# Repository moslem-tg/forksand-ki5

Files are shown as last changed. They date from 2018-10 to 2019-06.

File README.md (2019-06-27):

# ki5 RISC-V PCB in KiCAD

The ki5 board is a KiCAD port of SiFive's HiFive Unleashed board for the
RISC-V processor.

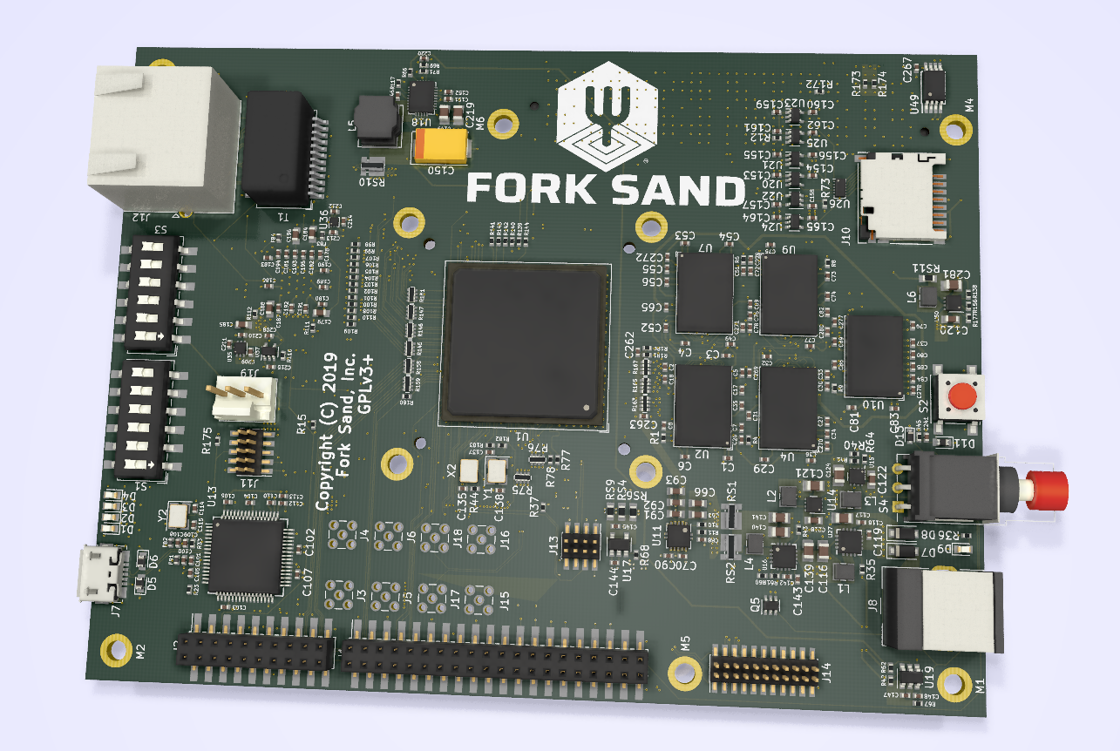
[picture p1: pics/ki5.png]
ki5 pic


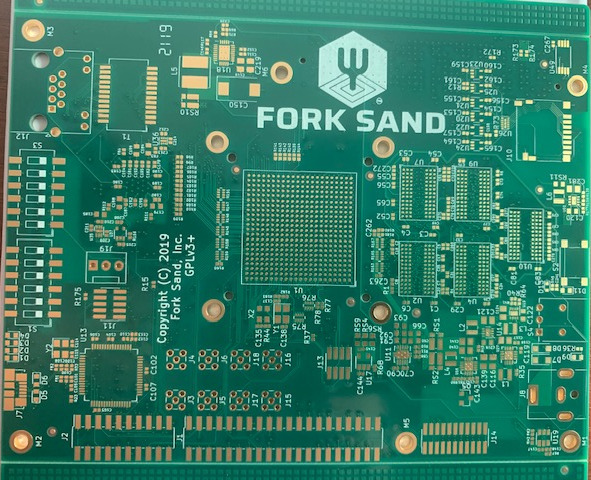
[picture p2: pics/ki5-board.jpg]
ki5 board pic


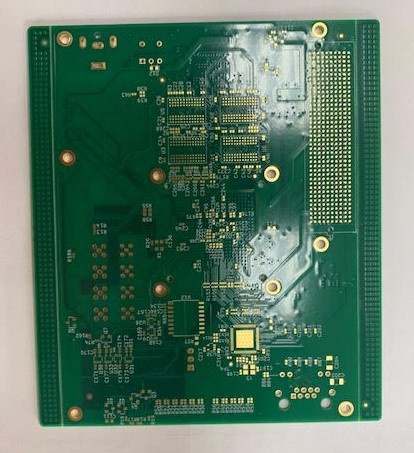
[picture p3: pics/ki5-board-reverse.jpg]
ki5 board reverse pic


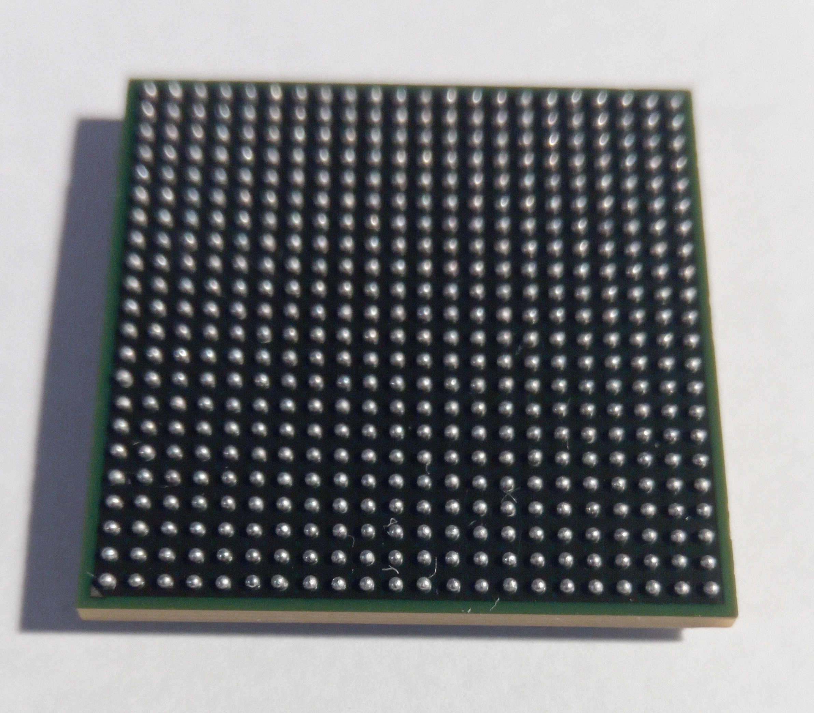
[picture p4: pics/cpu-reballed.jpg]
reballed cpu pic


First draft done for:

* Ethernet
* FMC Connector
* Power Supply
* USB to UART and JTAG
* Freedom U540 IO and Power
* DDR 4x8 32 bits
* DDR 4x8 32 bit and ECC
* Freedom U540 DDR and Chiplink
* First draft of the Board

It remains to finish and check power circuits for this list.

The second draft, release of the Board in progress.

(C) 2018, 2019, Fork Sand, Inc.

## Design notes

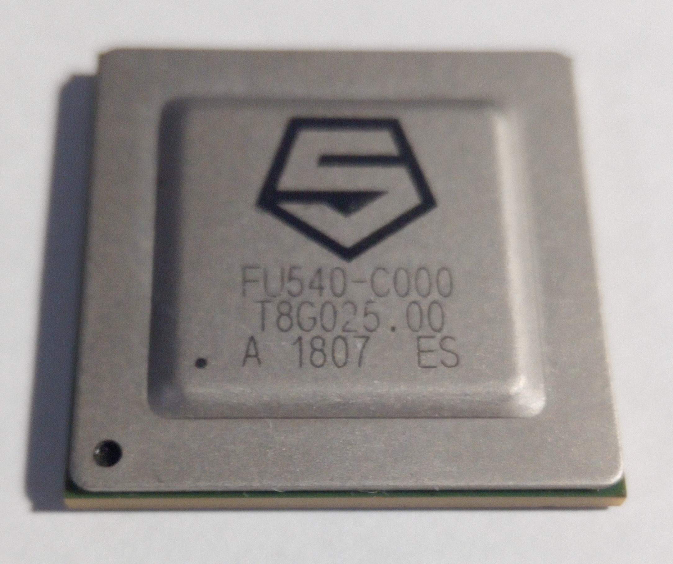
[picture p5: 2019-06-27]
pics/cpu-front.jpg

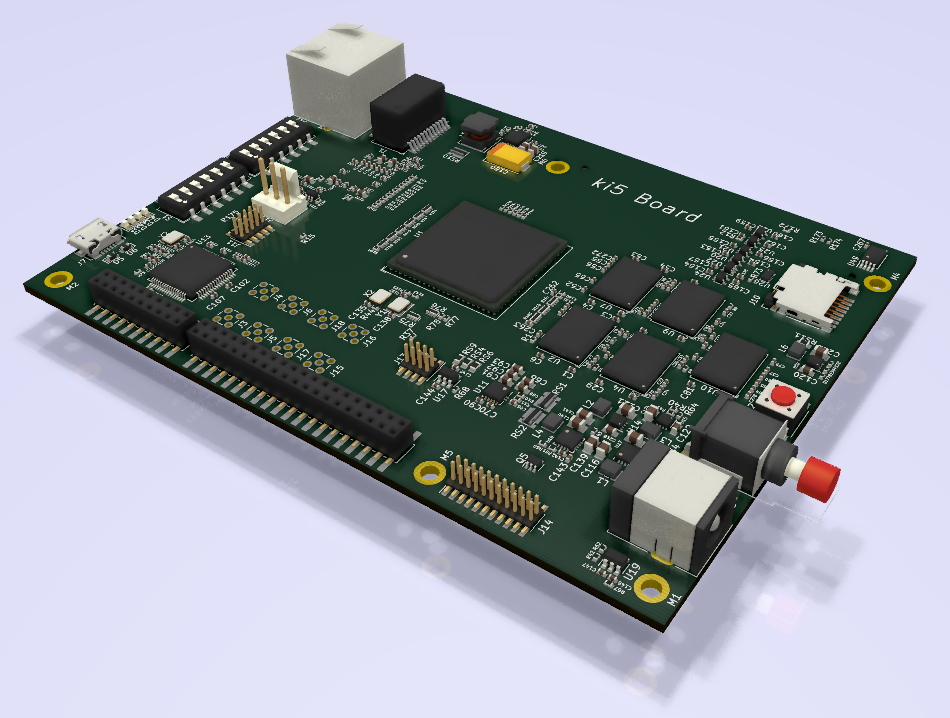
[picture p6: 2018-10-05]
3D/ki5_1.png

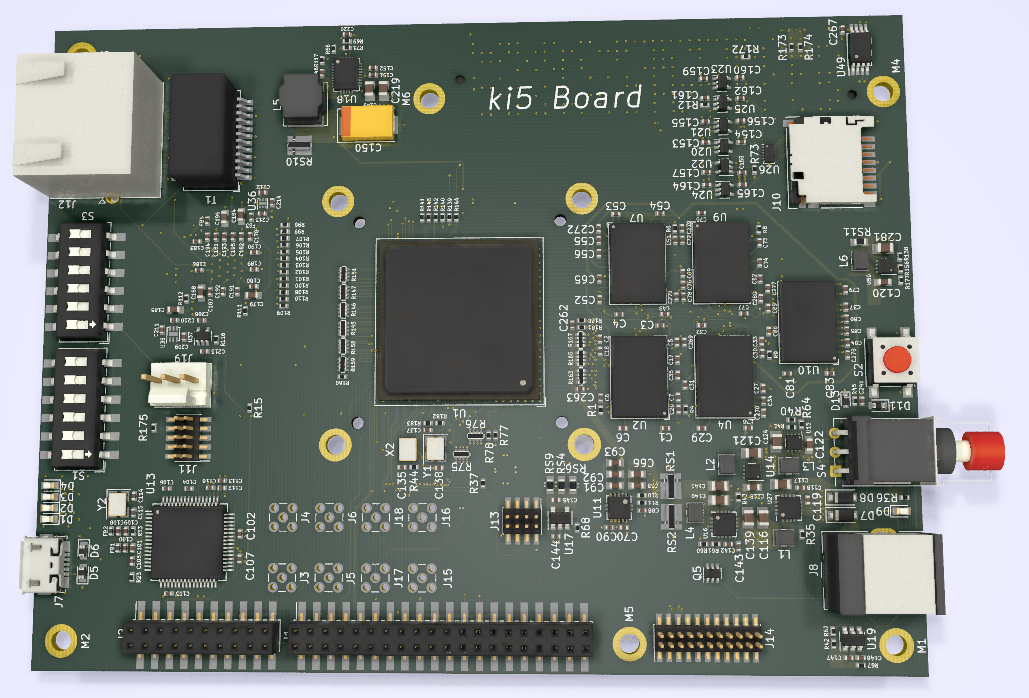
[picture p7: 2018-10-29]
3D/part of lines.png

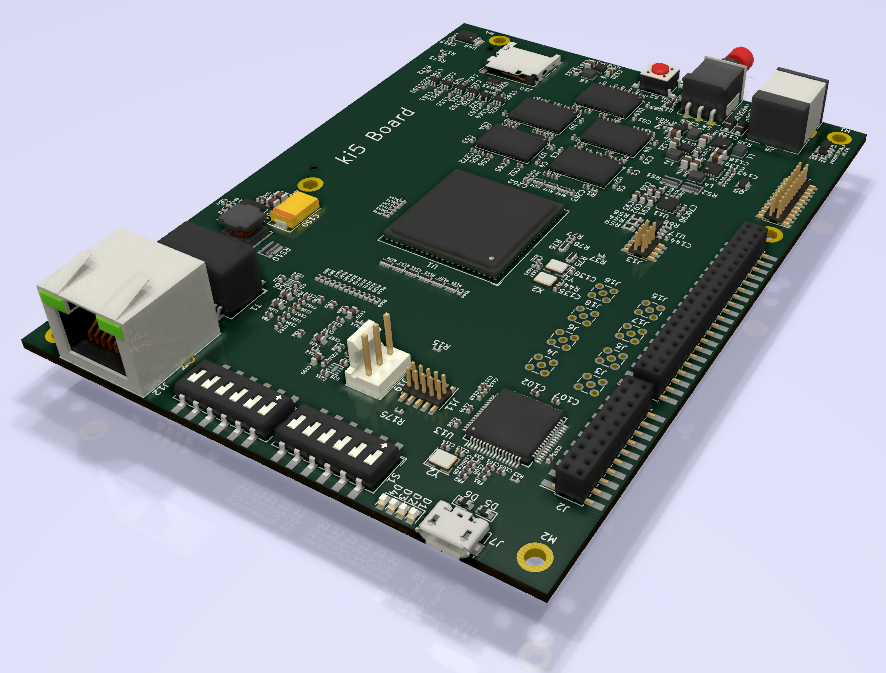
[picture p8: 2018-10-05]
3D/ki5_2.png

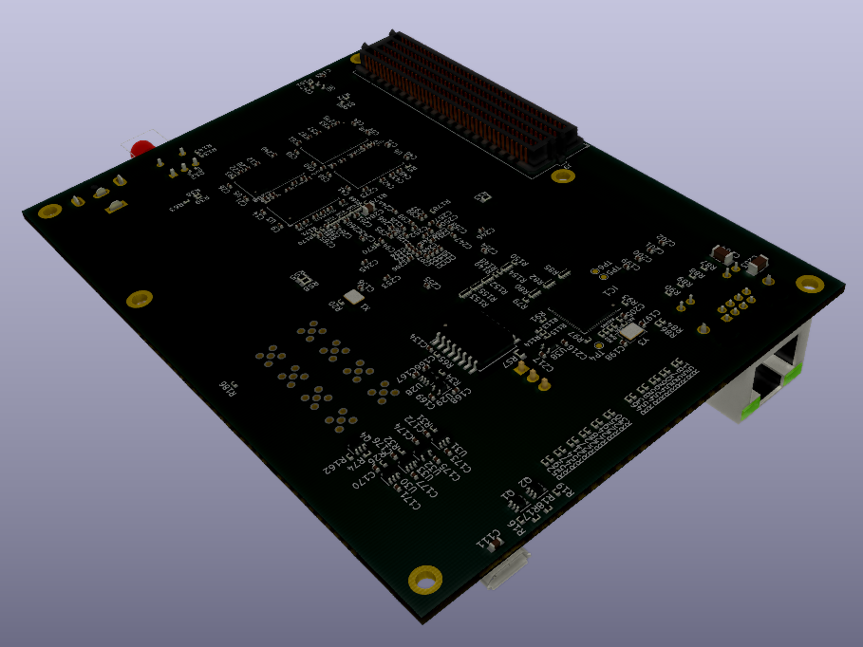
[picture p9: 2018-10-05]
3D/ki5_3.png

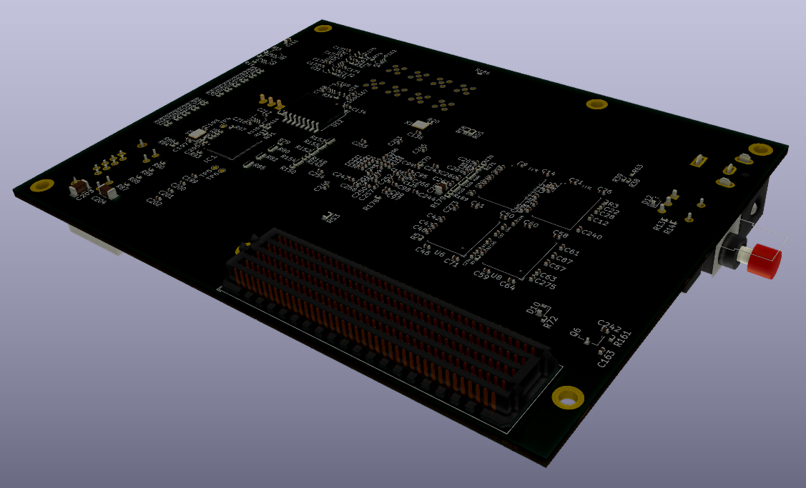
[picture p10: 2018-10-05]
3D/ki5_4.png

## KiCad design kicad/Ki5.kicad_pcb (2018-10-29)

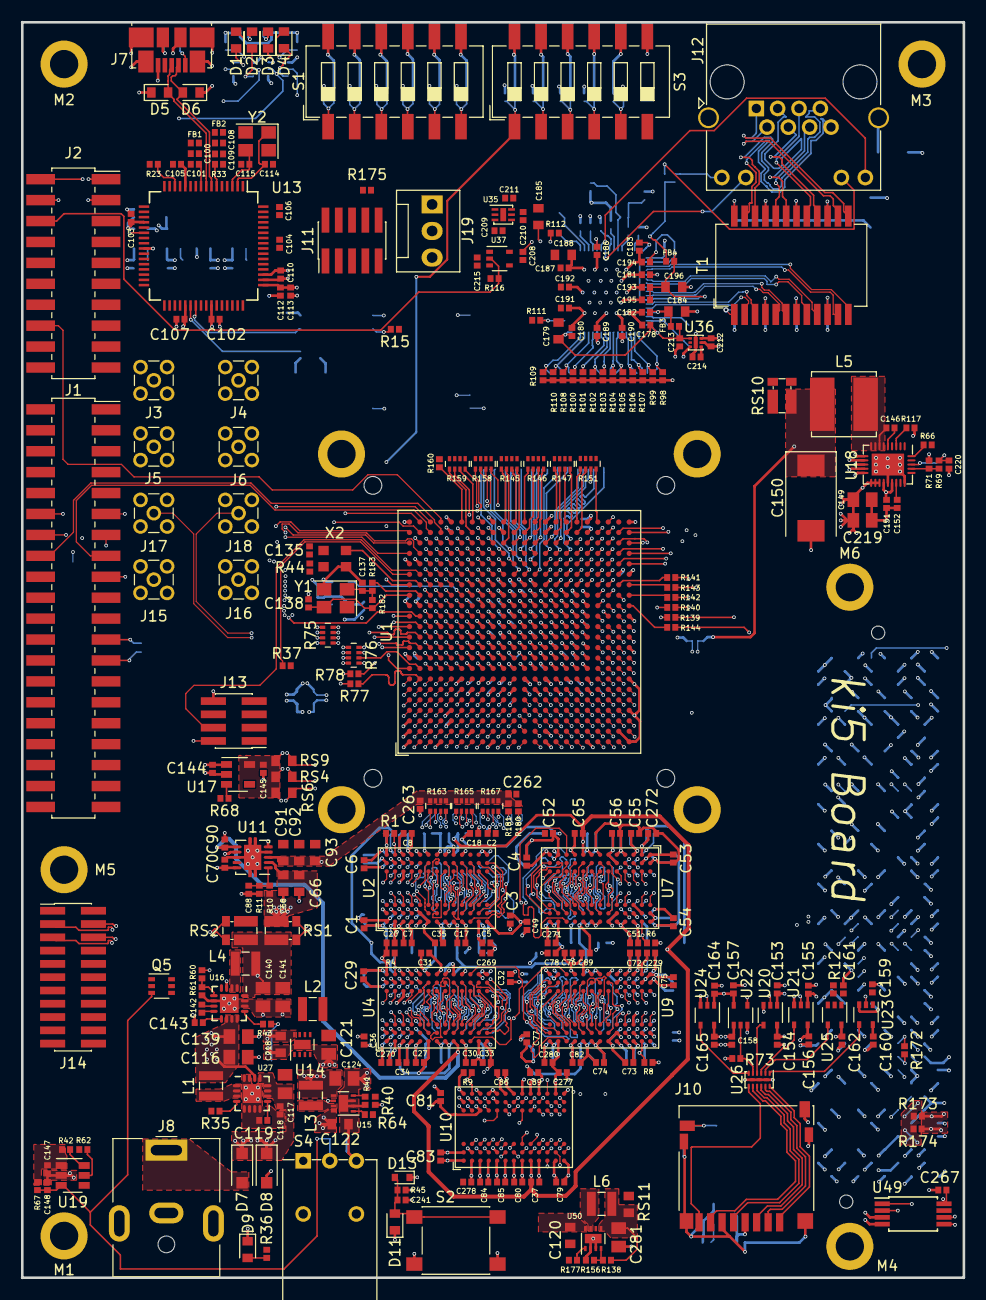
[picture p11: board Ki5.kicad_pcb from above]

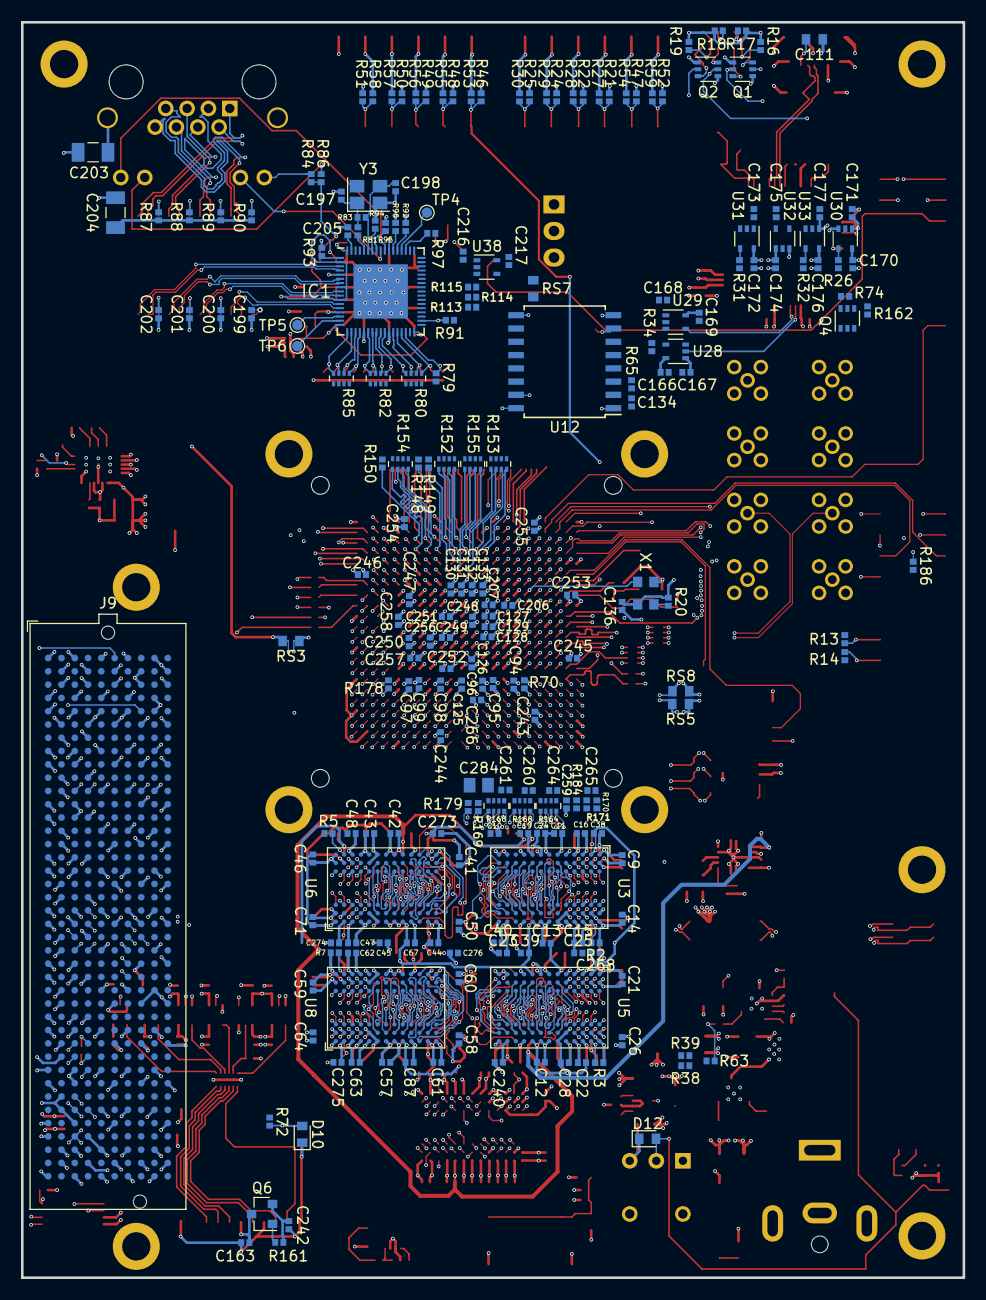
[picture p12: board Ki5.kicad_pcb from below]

Board: 10 copper layers, 90.0 x 120.0 mm, 542 parts (227 on the bottom side), 569 nets.

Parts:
C1, C6, C9, C14, C21, C26, C29, C34, C41, C46, C49, C54, C57, C62, C70, C71, C76, C79, C84, C94, C95, C96, C97, C100, C108, C112, C130, C131, C151, C163, C213, C243, C244, C245, C246, C247, C248, C249, C250, C251, C252: 4.7uF; C_0402_1005Metric
C2, C3, C4, C5, C7, C8, C10, C11, C12, C13, C15, C16, C17, C19, C22, C23, C24, C25, C27, C28, C30, C31, C32, C33, C35, C36, C37, C39, C42, C43, C44, C45, C47, C48, C50, C51, C52, C53, C55, C56, C58, C59, C60, C61, C63, C64, C65, C67, C69, C72, C73, C74, C75, C77, C78, C80, C81, C82, C83, C85, C86, C87, C89, C90, C98, C99, C101, C102, C103, C104, C105, C106, C107, C109, C110, C113, C118, C125, C126, C127, C129, C132, C133, C134, C135, C136, C146, C147, C153, C154, C155, C156, C157, C158, C159, C160, C161, C162, C164, C165, C166, C167, C168, C169, C170, C171, C172, C173, C174, C175, C176, C177, C178, C179, C181, C182, C183, C186, C188, C189, C190, C191, C192, C193, C194, C195, C199, C200, C201, C202, C206, C207, C208, C211, C214, C215, C216, C217, C220, C253, C254, C255, C256, C257, C258, C259, C260, C261, C262, C263, C264: 0.1uF; C_0402_1005Metric
C18, C20, C38, C40, C128, C144, C145, C209, C210, C212, C240, C242, C268, C269, C270, C271, C272, C273, C274, C275, C276, C277, C278, C279, C280: 1uF; C_0402_1005Metric
C66, C68, C91, C92, C93, C120, C122, C180, C184, C185, C187, C196, C218: 10uF; C_0603_1608Metric
C88: 1nF; C_0402_1005Metric
C111: 4.7uF; C_0603_1608Metric
C114, C115, C137, C138, C197, C198: 18pF; C_0402_1005Metric
C116, C121, C124, C139, C140, C141, C281: 22uF; C_0805_2012Metric
C117, C149, C219: 10uF; C_0805_2012Metric
C119: 33nF; C_0402_1005Metric
C142, C143, C148, C152, C205, C241, C265: 10nF; C_0402_1005Metric
C150: 220uF; CP_EIA-7343-20_Kemet-V
C203, C204: 1000pF, 2KV; C_1206_3216Metric
C266: 2.2pF; C_0402_1005Metric
C267: DNP; C_0402_1005Metric
C284: 0.1uF; C_0805_2012Metric
D1, D2, D3, D4, D9: Green; LED_0603_1608Metric
D5, D6, D10, D11, D12: PGB1010603NRHF; D_0603_1608Metric
D7: DB2W40300L; D_SOD-123F
D8: SMF12A; D_SOD-123F
D13: 1N4148WT; D_SOD-523
FB1, FB2, FB3, FB4: 120R; L_0402_1005Metric
IC1: VSC8541XMV-01; QFN-68-1EP_8x8mm_P0.4mm_EP5.2x5.2mm
J1: Conn_02x20_Odd_Even; PinSocket_2x20_P2.00mm_Vertical_SMD
J2: Conn_02x10_Odd_Even; PinSocket_2x10_P2.00mm_Vertical_SMD
J3, J4, J5, J6, J15, J16, J17, J18: Conn_Coaxial; MMCX_Molex_73415-1471_Vertical
J7: USB_B_Micro; USB_Micro-B_Molex_47346-0001
J8: Jack-DC; BarrelJack_CUI_PJ-063AH_Horizontal
J9: ASP-134602-01; Samtec_FMC_ASP-134602-01_10x40_P1.27mm_Vertical
J10: Micro_SD_Card_Det; microSD_HC_Hirose_DM3D-SF
J11: Conn_02x05_Odd_Even; PinHeader_2x05_P1.27mm_Vertical_SMD
J12: RJHSE5384; RJ45_Amphenol_RJHSE538X
J13: Conn_02x04_Odd_Even; PinHeader_2x04_P1.27mm_Vertical_SMD
J14: Conn_02x11_Odd_Even; PinHeader_2x11_P1.27mm_Vertical_SMD
J19: Fan_Tacho; FanPinHeader_1x03_P2.54mm_Vertical
L1: 1.0uH; L_Wuerth_MAPI-2512
L2, L3, L6: 2.2uH; L_Wuerth_MAPI-2512
L4: 0.47uH; L_Wuerth_MAPI-2510
L5: 1.0uH; L_Bourns_SRN6045TA
M1, M2, M3, M4, M5, M6: Mounting_Hole_PAD; MountingHole_2.7mm_M2.5_ISO7380_Pad
Q1, Q2, Q4, Q5: FDG6335N; SOT-363_SC-70-6
Q6: IRLML6402; SOT-23
R1, R2, R3, R4, R5, R6, R7, R8, R9, R70: 240R; R_0402_1005Metric
R10, R11, R107, R109, R111, R115: 10K; R_0402_1005Metric
R12, R20, R37, R40, R42, R44, R45, R62, R67, R69, R72, R74, R116, R161, R162: 100K; R_0402_1005Metric
R13, R14, R93: 2K; R_0402_1005Metric
R15: 47K; R_0402_1005Metric
R16, R17, R18, R19, R36, R84, R86: 330R; R_0402_1005Metric
R21, R22, R24, R25, R47, R52, R53, R55, R56, R57, R58, R73, R96, R113, R114: 4.7K; R_0402_1005Metric
R23, R33: 12K; R_0402_1005Metric
R26, R31, R32, R34: 1K; R_0402_1005Metric
R27, R28, R29, R30, R35, R46, R48, R49, R50, R51, R54, R59, R97, R98, R99, R100, R101, R102, R103, R104, R105, R106, R108, R110, R112: DNP; R_0402_1005Metric
R38: 210K; R_0402_1005Metric
R39, R41, R156: 33.2K; R_0402_1005Metric
R43, R63, R64, R65, R66, R68, R92, R94, R95, R117, R172, R173, R174, R175, R177, R183, R186: 0R; R_0402_1005Metric
R60: 80.6K; R_0402_1005Metric
R61: 160K; R_0402_1005Metric
R71: 82K; R_0402_1005Metric
R75, R76, R80, R82, R85, R145, R146, R147, R151, R152, R153, R154, R155, R158, R159: 33R; R_Array_Concave_4x0402
R77, R78, R79, R91, R139, R140, R141, R142, R143, R144, R148, R149, R150, R160: 33R; R_0402_1005Metric
R81: 39R; R_0402_1005Metric
R83, R182: 1M; R_0402_1005Metric
R87, R88, R89, R90, R178: 75R; R_0402_1005Metric
R138: 154K; R_0402_1005Metric
R163, R164, R165, R166, R167, R168: 49R9; R_Array_Convex_4x0402
R169, R170, R171, R179, R180, R181, R184: 49R9; R_0402_1005Metric
RS1, RS2, RS10: 0R001; R_Shunt_Vishay_WSKW0612
RS3, RS4, RS5, RS6, RS7, RS8, RS9: 0R20; R_0603_1608Metric
RS11: 0R02; R_0603_1608Metric
S1: SW DIP-6; SW_DIP_SPSTx06_Slide_6.7x16.8mm_W8.61mm_P2.54mm_LowProfile
S2: SW_Push; SW_SPST_PTS645
S3: DNP; SW_DIP_SPSTx06_Slide_6.7x16.8mm_W8.61mm_P2.54mm_LowProfile
S4: SW_Push_SPDT; SW_NKK_BB15AH
T1: TG111-MSC13LF; Transformer_Ethernet_HALO_TG111-MSC13
TP4, TP5, TP6: Test_Point; TestPoint_Pad_D1.0mm
U1: FU540-C000; BGA-484_23.0x23.0mm_Layout22x22_P1.0mm
U2, U3, U4, U5, U6, U7, U8, U9, U10: H5AN8G8NAFR-UH; FBGA-78_7.5x11mm_Layout2x3x13_P0.8mm
U11: TPS51200DRC; Texas_S-PVSON-N10
U12: IS25WP256D; SOIC-16W_7.5x10.3mm_P1.27mm
U13: FT2232HL; LQFP-64_10x10mm_P0.5mm
U14, U50: TLV62080DSGx; WSON-8-1EP_2x2mm_P0.5mm_EP0.9x1.6mm
U15: TLV62084DSGx; WSON-8-1EP_2x2mm_P0.5mm_EP0.9x1.6mm
U16: TLV62095RGTR; QFN-16-1EP_3x3mm_P0.5mm_EP1.8x1.8mm
U17: LP5907MFX-1.8/NOPB; SOT-23-5
U18: TPS51363; Texas_R-VFQFN-28-1EP_3.5x4.5mm_P0.4mm_EP2.1x3.1mm
U19: LM3880MFE-1AA/NOPB; SOT-23-6
U20, U21, U22, U23, U24, U25, U28, U29, U30, U31, U32, U33, U37, U38: SN74AUP1T34DCKR; SOT-353_SC-70-5
U26: TPD6F003; Texas_R-PWSON-N12_EP0.4x2mm
U27: TPS62133RGTT; QFN-16-1EP_3x3mm_P0.5mm_EP1.8x1.8mm
U35: MIC5353-2.5YMT-TR; MLF-6-1EP_1.6x1.6mm_P0.5mm_EP0.5x1.26mm
U36: NCP133AMX100TCG; DFN-6-1EP_1.2x1.2mm_P0.4mm_EP0.3x0.94mm
U49: M24C02-WMN; TSSOP-8_4.4x3mm_P0.65mm
X1: 33.3333 MHz; Oscillator_SMD_EuroQuartz_XO32-4Pin_3.2x2.5mm
X2: 1.0 MHz; Oscillator_SMD_EuroQuartz_XO32-4Pin_3.2x2.5mm
Y1: 33.333 MHz; Crystal_SMD_3225-4Pin_3.2x2.5mm
Y2: 12 MHz; Crystal_SMD_Abracon_ABM8G-4Pin_3.2x2.5mm
Y3: 25 MHz; Crystal_SMD_SeikoEpson_FA238-4Pin_3.2x2.5mm

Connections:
+1V0: C178.1, C179.1, C180.2, C213.1, FB3.1, IC1.17, IC1.34, U36.1
+1V2: C1.2, C2.2, C3.2, C4.2, C5.2, C6.2, C7.2, C8.2, C9.2, C10.2, C11.2, C12.2, C13.2, C14.2, C15.2, C16.2, C21.2, C22.2, C23.2, C24.2, C25.2, C26.2, C27.2, C28.2, C29.2, C30.2, C31.2, C32.2, C33.2, C34.2, C35.2, C36.2, C41.2, C42.2, C43.2, C44.1, C45.2, C46.2, C47.2, C48.2, C49.2, C50.2, C51.2, C52.2, C53.2, C54.2, C55.2, C56.2, C57.2, C58.2, C59.2, C60.2, C61.2, C62.2, C63.2, C64.2, C66.2, C68.2, C71.2, C72.2, C73.2, C74.2, C75.2, C76.2, C77.2, C78.2, C79.2, C80.2, C81.2, C82.2, C83.2, C84.2, C85.2, C86.2, R10.1, RS1.1, U2.A1, U2.B2, U2.B8, U2.C1, U2.C7, U2.C9, U2.E2, U2.E8, U2.F1, U2.F9, U2.H1, U2.J9, U2.M1, U2.N9, U3.A1, U3.B2, U3.B8, U3.C1, U3.C7, U3.C9, U3.E2, U3.E8, U3.F1, U3.F9, U3.H1, U3.J9, U3.M1, U3.N9, U4.A1, U4.B2, U4.B8, U4.C1, U4.C7, U4.C9, U4.E2, U4.E8, U4.F1, U4.F9, U4.H1, U4.J9, U4.M1, U4.N9, U5.A1, U5.B2, U5.B8, U5.C1, U5.C7, U5.C9, U5.E2, U5.E8, U5.F1, U5.F9, U5.H1, U5.J9, U5.M1, U5.N9, U6.A1, U6.B2, U6.B8, U6.C1, U6.C7, U6.C9, U6.E2, U6.E8, U6.F1, U6.F9, U6.H1, U6.J9, U6.M1, U6.N9, U7.A1, U7.B2, U7.B8, U7.C1, U7.C7, U7.C9, U7.E2, U7.E8, U7.F1, U7.F9, U7.H1, U7.J9, U7.M1, U7.N9, U8.A1, U8.B2, U8.B8, U8.C1, U8.C7, U8.C9, U8.E2, U8.E8, U8.F1, U8.F9, U8.H1, U8.J9, U8.M1, U8.N9, U9.A1, U9.B2, U9.B8, U9.C1, U9.C7, U9.C9, U9.E2, U9.E8, U9.F1, U9.F9, U9.H1, U9.J9, U9.M1, U9.N9, U10.A1, U10.B2, U10.B8, U10.C1, U10.C7, U10.C9, U10.E2, U10.E8, U10.F1, U10.F9, U10.H1, U10.J9, U10.M1, U10.N9, U11.2
+2V5: C185.2, C186.1, C208.1, C210.2, C216.1, FB4.1, IC1.58, R84.2, R86.2, R112.1, U35.4, U37.5, U38.1
+3.3VA: C163.2, J10.4, Q6.3
+3.3VP: C267.2, J9.D32, U49.8
+3V3: C70.2, C102.2, C103.2, C104.2, C110.2, C121.2, C144.1, C154.1, C156.1, C158.1, C160.1, C162.1, C165.1, C167.2, C169.2, C171.2, C173.2, C175.2, C177.2, C209.2, C242.2, FB1.2, FB2.2, L2.2, Q6.2, R16.1, R17.1, R18.1, R19.1, R23.1, R36.2, R38.2, R73.1, R74.2, R161.2, U11.7, U11.10, U13.20, U13.31, U13.42, U13.50, U13.56, U14.5, U17.1, U20.5, U21.5, U22.1, U23.5, U24.5, U25.5, U28.1, U29.5, U30.1, U31.1, U32.5, U33.1, U35.1, U35.3
+5V: C116.2, C120.2, C122.2, C139.2, C147.2, C151.1, C214.1, C218.2, J1.3, L1.2, R35.2, R42.2, R62.2, R67.2, U14.8, U15.8, U16.3, U16.10, U16.11, U16.12, U18.18, U18.20, U19.1, U27.14, U36.4, U50.8
+12V: C117.2, C118.2, C149.2, C219.2, D7.1, D8.1, J1.4, J1.6, J19.2, R173.2, R174.2, U18.15, U18.16, U18.17, U27.10, U27.11, U27.12, U27.13
/DDR4_x8_32b_1/REFIN: C88.1, R10.2, R11.1, U11.1
/Ethernet/CLKOUT: IC1.54, R97.2, R112.2
/Ethernet/CLK_SQUELCH_IN: IC1.57, R96.1
/Ethernet/COL: IC1.18, R85.4, R98.2
/Ethernet/CRS: IC1.19, R85.3, R99.2
/Ethernet/ELED0: IC1.60, J12.10
/Ethernet/ELED1: IC1.59, J12.12
/Ethernet/FASTLINK_FAIL_2V5: IC1.52, U38.2
/Ethernet/GEMGXL_MDINT: IC1.51, R115.2
/Ethernet/GEMGXL_RST_2V5: IC1.53, U37.4
/Ethernet/MX1_N: J12.7, T1.22
/Ethernet/MX1_P: J12.8, T1.23
/Ethernet/MX2_N: J12.3, T1.19
/Ethernet/MX2_P: J12.6, T1.20
/Ethernet/MX3_N: J12.4, T1.16
/Ethernet/MX3_P: J12.5, T1.17
/Ethernet/MX4_N: J12.1, T1.13
/Ethernet/MX4_P: J12.2, T1.14
/Ethernet/P0_D0_N: IC1.12, T1.3
/Ethernet/P0_D0_P: IC1.13, T1.2
/Ethernet/P0_D1_N: IC1.9, T1.6
/Ethernet/P0_D1_P: IC1.10, T1.5
/Ethernet/P0_D2_N: IC1.6, T1.9
/Ethernet/P0_D2_P: IC1.7, T1.8
/Ethernet/P0_D3_N: IC1.3, T1.12
/Ethernet/P0_D3_P: IC1.4, T1.11
/Ethernet/RXD0: IC1.29, R80.3, R100.2
/Ethernet/RXD1: IC1.27, R80.4, R101.2
/Ethernet/RXD2: IC1.26, R82.1, R102.2
/Ethernet/RXD3: IC1.25, R82.2, R103.2
/Ethernet/RXD4: IC1.24, R82.3, R104.2
/Ethernet/RXD5: IC1.23, R82.4, R105.2
/Ethernet/RXD6: IC1.21, R85.1, R106.2
/Ethernet/RXD7: IC1.20, R85.2, R107.2
/Ethernet/RX_CLK: IC1.32, R79.1, R109.2
/Ethernet/RX_DV: IC1.30, R80.2, R108.2
/Ethernet/RX_ER: IC1.31, R80.1, R110.2
/Ethernet/TX_CLK: IC1.36, R91.1, R111.2
/FMC.sch/FMC_GA0: J9.C34, U49.1
/FMC.sch/FMC_GA1: J9.D35, U49.2
/FMC.sch/FMC_SCL: J9.C30, U49.6
/FMC.sch/FMC_SDA: J9.C31, U49.5
/FT2232/FT_JTAG_SRST: Q4.6, R74.1, U13.22
/FT2232/FT_JTAG_TCK: U13.16, U30.2
/FT2232/FT_JTAG_TDI: U13.17, U31.2
/FT2232/FT_JTAG_TDO: U13.18, U32.4
/FT2232/FT_JTAG_TMS: U13.19, U33.2
/FT2232/FT_UART_RX: U13.39, U29.4
/FT2232/FT_UART_TX: U13.38, U28.2
/FT2232/USB_D_N: D6.2, J7.2, U13.7
/FT2232/USB_D_P: D5.2, J7.3, U13.8
/FT2232/VPHY_FT: C108.2, C109.2, FB2.1, U13.4
/FT2232/VPLL_FT: C100.2, C101.2, FB1.1, U13.9
/Freedom-U540_1/CHIPLINK_TX_CLK_R: R148.2, U1.P19
/Freedom-U540_1/CHIPLINK_TX_DAT0_R: R154.1, U1.T19
/Freedom-U540_1/CHIPLINK_TX_DAT1_R: R154.3, U1.R19
/Freedom-U540_1/CHIPLINK_TX_DAT2_R: R152.2, U1.N18
/Freedom-U540_1/CHIPLINK_TX_DAT3_R: R154.2, U1.R20
/Freedom-U540_1/CHIPLINK_TX_DAT4_R: R154.4, U1.P20
/Freedom-U540_1/CHIPLINK_TX_DAT5_R: R151.3, U1.U20
/Freedom-U540_1/CHIPLINK_TX_DAT6_R: R152.3, U1.N19
/Freedom-U540_1/CHIPLINK_TX_DAT7_R: R151.1, U1.U22
/Freedom-U540_1/CHIPLINK_TX_DAT8_R: R147.2, U1.R21
/Freedom-U540_1/CHIPLINK_TX_DAT9_R: R151.4, U1.W22
/Freedom-U540_1/CHIPLINK_TX_DAT10_R: R147.3, U1.T22
/Freedom-U540_1/CHIPLINK_TX_DAT11_R: R151.2, U1.U21
/Freedom-U540_1/CHIPLINK_TX_DAT12_R: R152.4, U1.M20
/Freedom-U540_1/CHIPLINK_TX_DAT13_R: R147.4, U1.T21
/Freedom-U540_1/CHIPLINK_TX_DAT14_R: R146.3, U1.N22
/Freedom-U540_1/CHIPLINK_TX_DAT15_R: R155.1, U1.M17
/Freedom-U540_1/CHIPLINK_TX_DAT16_R: R146.4, U1.N21
/Freedom-U540_1/CHIPLINK_TX_DAT17_R: R147.1, U1.R22
/Freedom-U540_1/CHIPLINK_TX_DAT18_R: R145.4, U1.L21
/Freedom-U540_1/CHIPLINK_TX_DAT19_R: R155.4, U1.M18
/Freedom-U540_1/CHIPLINK_TX_DAT20_R: R155.3, U1.L20
/Freedom-U540_1/CHIPLINK_TX_DAT21_R: R152.1, U1.N20
/Freedom-U540_1/CHIPLINK_TX_DAT22_R: R146.1, U1.M22
/Freedom-U540_1/CHIPLINK_TX_DAT23_R: R155.2, U1.M19
/Freedom-U540_1/CHIPLINK_TX_DAT24_R: R145.2, U1.K20
/Freedom-U540_1/CHIPLINK_TX_DAT25_R: R146.2, U1.M21
/Freedom-U540_1/CHIPLINK_TX_DAT26_R: R145.1, U1.K22
/Freedom-U540_1/CHIPLINK_TX_DAT27_R: R153.2, U1.L19
/Freedom-U540_1/CHIPLINK_TX_DAT28_R: R153.4, U1.K19
/Freedom-U540_1/CHIPLINK_TX_DAT29_R: R145.3, U1.L22
/Freedom-U540_1/CHIPLINK_TX_DAT30_R: R153.3, U1.L18
/Freedom-U540_1/CHIPLINK_TX_DAT31_R: R153.1, U1.L17
/Freedom-U540_1/CHIPLINK_TX_RST_R: R150.2, U1.T20
/Freedom-U540_1/CHIPLINK_TX_SEND_R: R149.2, U1.N17
/Freedom-U540_1/GEMGXL_TXD0_R: R75.8, U1.B12
/Freedom-U540_1/GEMGXL_TXD1_R: R75.7, U1.C11
/Freedom-U540_1/GEMGXL_TXD2_R: R75.6, U1.D11
/Freedom-U540_1/GEMGXL_TXD3_R: R75.5, U1.F11
/Freedom-U540_1/GEMGXL_TXD4_R: R76.8, U1.C10
/Freedom-U540_1/GEMGXL_TXD5_R: R76.7, U1.D10
/Freedom-U540_1/GEMGXL_TXD6_R: R76.6, U1.B8
/Freedom-U540_1/GEMGXL_TXD7_R: R76.5, U1.D9
/Freedom-U540_1/GEMGXL_TX_EN_R: R77.1, U1.B7
/Freedom-U540_1/GEMGXL_TX_ER_R: R78.1, U1.F10
/Freedom-U540_1/IO_DDR_RSVD0: J15.1, U1.E8
/Freedom-U540_1/IO_DDR_RSVD1: J16.1, U1.D8
/Freedom-U540_1/IO_DDR_RSVD2: J17.1, U1.F8
/Freedom-U540_1/IO_DDR_RSVD3: J18.1, U1.F9
/Freedom-U540_2/EN_VDD_SD: J2.10, Q4.5, R162.2, U1.B22
/Freedom-U540_2/GPIO0: J1.17, U1.F17
/Freedom-U540_2/GPIO1: J1.18, U1.C22
/Freedom-U540_2/GPIO2: J1.15, U1.C21
/Freedom-U540_2/GPIO3: J1.16, U1.D21
/Freedom-U540_2/GPIO4: J1.13, U1.E18
/Freedom-U540_2/GPIO5: J1.14, U1.D20
/Freedom-U540_2/GPIO6: J1.11, U1.E20
/Freedom-U540_2/GPIO7: J1.12, U1.C20
/Freedom-U540_2/GPIO8: J1.9, U1.D19
/Freedom-U540_2/GPIO9: J1.10, U1.A21
/Freedom-U540_2/GPIO10: R186.1, U1.F18
/Freedom-U540_2/GPIO15: J1.7, U1.G17
/Freedom-U540_2/HFXCLKIN: U1.F15, X1.3
/Freedom-U540_2/HFXSEL: R52.2, R59.1, S1.1, U1.C15
/Freedom-U540_2/I2C0_SCL: J1.25, R14.2, U1.Y14
/Freedom-U540_2/I2C0_SDA: J1.23, R13.2, U1.W13
/Freedom-U540_2/IO_PRCI_RSVD0: R46.2, R53.1, S3.1, U1.A16
/Freedom-U540_2/IO_PRCI_RSVD1: R48.2, R55.1, S3.2, U1.D13
/Freedom-U540_2/IO_PRCI_RSVD2: J3.1, U1.E13
/Freedom-U540_2/IO_PRCI_RSVD3: J13.1, U1.D16
/Freedom-U540_2/IO_PRCI_RSVD4: J13.2, U1.C16
/Freedom-U540_2/IO_PRCI_RSVD5: J13.3, U1.E15
/Freedom-U540_2/IO_PRCI_RSVD6: J13.4, U1.B17
/Freedom-U540_2/IO_PRCI_RSVD7: J13.5, U1.G13
/Freedom-U540_2/IO_PRCI_RSVD8: J13.6, U1.H13
/Freedom-U540_2/IO_PRCI_RSVD9: J13.7, U1.E16
/Freedom-U540_2/IO_PRCI_RSVD10: R49.2, R56.1, S3.3, U1.D17
/Freedom-U540_2/IO_PRCI_RSVD11: R51.2, R58.1, S3.5, U1.D14
/Freedom-U540_2/IO_PRCI_RSVD12: R50.2, R57.1, S3.4, U1.E14
/Freedom-U540_2/IO_PRCI_RSVD13: J4.1, U1.F14
/Freedom-U540_2/IO_PRCI_RSVD14: J5.1, U1.F13
/Freedom-U540_2/IO_PRCI_RSVD15: J6.1, U1.C14
/Freedom-U540_2/MSEL0: R21.2, R27.1, S1.3, U1.A19
/Freedom-U540_2/MSEL1: R22.2, R28.1, S1.4, U1.C18
/Freedom-U540_2/MSEL2: R24.2, R29.1, S1.5, U1.A20
/Freedom-U540_2/MSEL3: R25.2, R30.1, S1.6, U1.B19
/Freedom-U540_2/PWM0_0: J2.2, Q1.2, U1.G19
/Freedom-U540_2/PWM0_1: J2.4, Q1.5, U1.F21
/Freedom-U540_2/PWM0_2: J2.1, Q2.2, U1.F20
/Freedom-U540_2/PWM0_3: J2.3, Q2.5, U1.G20
/Freedom-U540_2/PWM1_0: J2.16, U1.D22
/Freedom-U540_2/PWM1_1: J2.18, U1.H17
/Freedom-U540_2/PWM1_2: J2.17, U1.G18
/Freedom-U540_2/PWM1_3: J2.19, U1.F19
/Freedom-U540_2/QSPI0_CS: R15.2, U1.J19, U12.7
/Freedom-U540_2/QSPI0_DQ0: U1.H21, U12.15
/Freedom-U540_2/QSPI0_DQ1: U1.H22, U12.8
/Freedom-U540_2/QSPI0_DQ2: U1.J21, U12.9
/Freedom-U540_2/QSPI0_DQ3: U1.H20, U12.1
/Freedom-U540_2/QSPI0_SCK: U1.K18, U12.16
/Freedom-U540_2/QSPI1_CS0: R158.4, U1.K17
/Freedom-U540_2/QSPI1_CS0_R: J1.30, R158.5
/Freedom-U540_2/QSPI1_CS1: R159.1, U1.G21
/Freedom-U540_2/QSPI1_CS1_R: J2.9, R159.8
/Freedom-U540_2/QSPI1_CS2: R159.4, U1.H19
/Freedom-U540_2/QSPI1_CS2_R: J2.11, R159.5
/Freedom-U540_2/QSPI1_CS3: R158.2, U1.J20
/Freedom-U540_2/QSPI1_CS3_R: J2.13, R158.7
/Freedom-U540_2/QSPI1_DQ0: R159.3, U1.G22
/Freedom-U540_2/QSPI1_DQ0_R: J1.28, R159.6
/Freedom-U540_2/QSPI1_DQ1: R158.1, U1.J18
/Freedom-U540_2/QSPI1_DQ1_R: J1.32, R158.8
/Freedom-U540_2/QSPI1_DQ2: R160.2, U1.F22
/Freedom-U540_2/QSPI1_DQ2_R: J2.5, R160.1
/Freedom-U540_2/QSPI1_DQ3: R158.3, U1.J17
/Freedom-U540_2/QSPI1_DQ3_R: J2.7, R158.6
/Freedom-U540_2/QSPI1_SCK: R159.2, U1.H18
/Freedom-U540_2/QSPI1_SCK_R: J1.34, R159.7
/Freedom-U540_2/QSPI2_CS: R144.2, U1.AB14
/Freedom-U540_2/QSPI2_CS_3V3: U25.4, U26.2
/Freedom-U540_2/QSPI2_CS_CON: J10.2, U26.11
/Freedom-U540_2/QSPI2_CS_R: R12.1, R144.1, U25.2
/Freedom-U540_2/QSPI2_HOLD: R140.2, U1.Y15
/Freedom-U540_2/QSPI2_HOLD_3V3: U24.4, U26.6
/Freedom-U540_2/QSPI2_HOLD_CON: J10.8, U26.7
/Freedom-U540_2/QSPI2_HOLD_R: R140.1, U24.2
/Freedom-U540_2/QSPI2_MISO: R142.2, U1.AB15
/Freedom-U540_2/QSPI2_MISO_3V3: R73.2, U22.2, U26.5
/Freedom-U540_2/QSPI2_MISO_CON: J10.7, U26.8
/Freedom-U540_2/QSPI2_MISO_R: R142.1, U22.4
/Freedom-U540_2/QSPI2_MOSI: R141.2, U1.AA16
/Freedom-U540_2/QSPI2_MOSI_3V3: U21.4, U26.3
/Freedom-U540_2/QSPI2_MOSI_CON: J10.3, U26.10
/Freedom-U540_2/QSPI2_MOSI_R: R141.1, U21.2
/Freedom-U540_2/QSPI2_SCK: R139.2, U1.W15
/Freedom-U540_2/QSPI2_SCK_3V3: U20.4, U26.4
/Freedom-U540_2/QSPI2_SCK_CON: J10.5, U26.9
/Freedom-U540_2/QSPI2_SCK_R: R139.1, U20.2
/Freedom-U540_2/QSPI2_WP: R143.2, U1.AB16
/Freedom-U540_2/QSPI2_WP_3V3: U23.4, U26.1
/Freedom-U540_2/QSPI2_WP_CON: J10.1, U26.12
/Freedom-U540_2/QSPI2_WP_R: R143.1, U23.2
/Freedom-U540_2/RTCXALTCLKIN: U1.B16, X2.3
/Freedom-U540_2/RTCXSEL: R47.2, R54.1, S1.2, U1.D15
/Freedom-U540_2/SD_CD: D10.2, J2.12, J10.9, R72.1, U1.B20
/Freedom-U540_2/UART1_RX: J1.27, U1.AA14
/Freedom-U540_2/UART1_TX: J1.29, U1.AA15
/Power.sch/EN_1V8: R64.1, U15.1
/Power.sch/EN_3V3: R63.1, U14.1
/Power.sch/EN_CORE: R66.1, U18.28
/Power.sch/EN_DDR: R43.1, U16.13
/Power.sch/EN_DDR_VPP: R177.1, U50.1
/Power.sch/EN_PLL: R68.1, U17.3
/Power.sch/PWR_EN1: R42.1, R43.2, R63.2, R64.2, R177.2, U19.6
/Power.sch/PWR_EN2: R62.1, R66.2, R68.2, U19.5
/Power.sch/PWR_ON: C148.2, D12.2, Q5.3, R67.1, S4.2, U19.3
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

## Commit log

2018-07-14 Added Freedom U540 DDR and Chiplink
    [Freedom-U540_1-SchDoc.sch]
2018-07-14 Изменить 'README.md'
2018-08-14 DDR4_x8_32b_1 updates
    [DDR4_x8_32b_1-SchDoc.sch]
2018-08-14 Updated according to the rules of the official KiCAD repo
    [Ethernet-SchDoc.sch, FMC-SchDoc.sch]
2018-08-17 Board first draft
    [Ki5.kicad_pcb]
2018-09-18 Bom updated
2018-10-02 Updated for 3D
    [Ki5.kicad_pcb]
2018-10-04 ki5 board 3D model
2018-10-22 Update kicad electric lines
    [DDR4_x8_32b_1-SchDoc.sch, DDR4_x8_32b_2_ECC-SchDoc.sch, Ethernet-SchDoc.sch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]
2018-12-24 Gerber files for ki5 update
    [Ki5-B.Cu.gbr, Ki5-B.Mask.gbr, Ki5-B.Paste.gbr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]
2018-12-31 Gerber update
    [Ki5-F.Mask.gbr, Ki5-F.Paste.gbr, Ki5-F.SilkS.gbr]
2019-01-11 Gerber files update
    [Ki5-In1.Cu.gbr, Ki5-In2.Cu.gbr, Ki5-In3.Cu.gbr]
2019-01-20 ki5 update
    [DDR4_x8_32b_1-SchDoc.sch, DDR4_x8_32b_2_ECC-SchDoc.sch, Ethernet-SchDoc.sch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]
2019-02-15 Add pic of board
2019-03-06 Gerber updates
    [Ki5-In5.Cu.gbr, Ki5-NPTH.drl]
2019-06-19 Add production spreadsheet, pic of board reverse
    [Ki5-production-info.ods]
